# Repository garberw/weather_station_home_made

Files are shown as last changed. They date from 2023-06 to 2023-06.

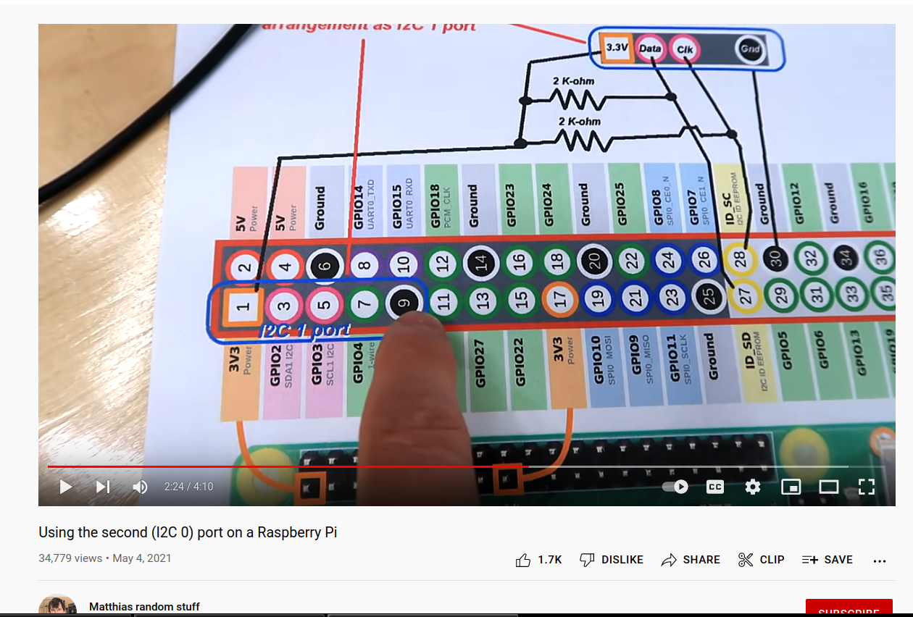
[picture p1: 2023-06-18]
raspi_user/weathere_python_service/util/Matthias_random_stuff_raspi_i2c_bus0.png

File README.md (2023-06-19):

# weather_station_home_made

Suite of two home made weather stations using raspberry pi and arduino.  Also third weather station with home made indoors part and Acurite Atlas outdoors part.  Designed for use with weewx software.  

You would need a great many parts to build any of these three weather stations.  Consequently I do not expect many people to use this github project directly.  If I had to recommend one of the three stations it would be "green".  This github project is useful for:
(A) people who have an interest in using weewx with more than one weather station
(B) people who are interested in modbus especially with weather sensors
(C) people who want examples of how to customize weewx

here is the general layout ...

(0) hostname weathers raspberry pi 4b is the weewx server.
The server accepts input from three weather stations (weewx_atlas, weewx_green, weewx_wmod).  The server stores weather data in a separate sqlite3 database for each weather station and produces a set of graphs every few minutes.  The graphs are available as web pages and weathers also runs an nginx webserver.  The weathers server should be manipulated remotely from a desktop.  All development should take place on the desktop (preferably in ~/git/weather_station_home_made/) and be pushed to weathers and the other raspis using the scripts in $GIT_HOME/bin/wg-arduino-* and $GIT_HOME/bin/wg-WEATHER-*.

(1) weewx_atlas (a weewxd systemd service)
Outdoors hardware is Acurite Atlas (TM).  The radio signal from the atlas is received by and RTL-SDR radio dongle hooked up by usb to weathers.  Weewx uses the weewx-sdr driver (not by me) which in turn uses rtl-433 (not by me) to control the dongle and read the radio data printed on the usb connection.  Indoors hardware is Arduino Adafruit ItsyBitsy M4 nicknamed wpa.  This wpa reads the indoors temperature, pressure and humidity using an Adafruit BOSCH bme688 breakout board.  The wpa Arduino is hooked up to weathers over another usb serial port ttyACMwa.  This is connected to weewx by a custom weewx service found in WEEWX/weewx-atlas.  This weather station has excellent uptime but it had a glitch:  gaps in the weewx database data due to nulls (python Nones).  The gaps were fixed by handling the indoors data with a weewx service I wrote.  The weewx-sdr driver and my service together keep pace with the input from the two usb ports as it arrives.

(2) weewx_green (a weewxd systemd service)
This was an attempt to make the most robust and simple weather station possible and it succeeded.  It has almost perfect uptime and no errors.
The outdoors part is a raspi02w with hostname weathere (for external) with I2C sensors for light and UV and an interrupt driven handler for the rain bucket switch.  Anemometer is made by the company Renke and has modbus output.  Also temperature is Taidacent SHT30 and has modbus output.  I wrote a tiny modbus library.  The outdoors raspi runs a systemd service also called "weathere".  This service controls all the sensors and simply prints the result to /tmp/weathere_final.dat.  The indoors part of the weather station is a raspi02w with hostname weatherg (for green) which is hooked up to an Adafruit Itsy Bitsy M4 Arduino which controls another BME688 temperature pressure and humidity sensor.  The weatherg runs a systemd service also called "weatherg".  This also simply prints the output from the bme688 on /tmp/weatherg_final.dat.  The driver for weewx simply scps (secure copies) the two files to weathers!  Stupid but flawless.

(3) weewx_wmod (a weewxd systemd service)
This is much more complicated.  Outdoors there are two modbus sensors:  the anemometer (same Renke model but currently absent) and the temperature and humidity sensor (another SHT30).  The original design was to place the light sensor separate to keep it out of the shade and so on for each sensor.  Connecting the modbus wires to the central outdoors modbus client (wpc) I had too many bad connections.  I would have to have better hardware to do this.  The light and the rain each had their own arduino (wpl and wpr) and acted as a modbus sensor/server; I just crammed them into the same enclosure as the client wpc and used shorter wires to connect them all.  The client wpc is also a LoRa radio transmitter and sends the signal to the indoors.  The wpw arduino indoors is the radio receiver.  It also has the indoors sensors (you guessed it another bme688).  The arduinos  have a much more complicated modbus library I wrote in c++.

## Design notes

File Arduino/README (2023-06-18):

TODO ================
timing when usb not plugged in;
ttyUSB; avrdude requires replug usb;
weewx driver; json; pack; unpack (parse);
power;
  diodes;
  and LoRa; check radio range;
fixed
rain is a pull down pin not a pull up;

ver56 ===============
updated error handling macros and added backtrace based on FUNC_BEGIN pushing
__func__name__ on a stack in static_serial_print; changed most macros from
ERROR_RETURN to ERROR_CONDITION which does backtrace; ERROR_CONDITION is
for point where error would originally be raised or thrown;
ERROR_RETURN is for returning function with subsidiary error in descendents;
ERROR_CATCH catches any errors that have happened so far accumulated in weather_exception;
weather_exception is reset at beginning of main loop;

ver55 ===============

ver54 ===============
added two locks LOCK1 and LOCK2 for FUNC_BEGIN which turns ser_print printing on or off
by looking up boolean value (on or off) in hash table of combinations (file + function)
names from variables defined by compiler next pushing on/off value on a stack;
LOCK1 is static and precomputes hash lookup based on variables on first execution
and not thereafter; LOCK2 just gets value stored in LOCK1; avoids computing hash at run time;
also simplified select* functions in weather_lib_wmod;
runs but not debugged extensively;

ver53 ===============
merge wdat and sdat into wdat including both indoors and outdoors;
pythonic index sets into wdat data table replace explicit repetitive pack and print statements;
now all printing of weather data except diagnostics is done by weather_data class / lib;
everything has new names supposed to be more symmetrical; more symmetrical structure;
all drivers patched; moved compilation to electron and all loads (flash arduino)
done by respective raspberry pi weathers (wpa; wpw;); weatherw (wpc; wpl; wpr;); weatherg (wpg);
option in "makefile" (wg-arduino-build.sh) to compile anything given load host and usb port;
this allows short test programs e.g. in ~/Arduino/utility_bug;
created ~/Arduino/deprecated for old stuff;
emacs supports makefile and "F5" "F2" and "shift F2" keys for global search and replace;
"symmetrical" names keep deprecated separate at top of "F5" list; mark whole directory "m"
then unmark deprecated "u" before search "F2";
created new udev rule that automatically sets baud and "stty -F raw" obviating need for "ssss"
alias (wg-arduino-stty.sh) script;
figured out how to reset with button on arduino; tap it twice quickly; should turn green;
added Adafruit watchdog timer;
runs but not debugged extensively;

ver52 ===============
a few minor changes; runs;

ver51 ===============
reverted to version 49 then developed automatic way of creating header file
to turn print statements on or off based on compiler "macros" (actually not
macros) __func__ and __FILE__; stored in hash table; look up at beginning of
each function; constructor LOCK pushes "in-use" on stack; destructor pops off
on function exit; to make it more efficient
(1) remove bounds check in in-use stack table lookup;
(2) remove redundant FUNC_BEGIN which call slow load (hash table lookup);
runs; not thoroughly debgugged; was crashing requiring reset button;

ver50 ===============
version with exception handling; never got it to work;
believe they may simply not be supported;
see calendar .o comments and "todo-done" log of work done in directory aa-aa;

ver49 ===============
I think it works; split atlas into atlas and green; no more compiler macros -D in
platform_local.txt or anywhere; created weather_indoors2 library
to copy and print iaq data to weewx; revised .emacs and ~/bin/wg-arduino-build.sh script;
compiles on weathers; rsync's everything then uploads remotely when needed;

ver48 ===============
bme688 working with iaq and co2 for all sensors; fixed; but set delay to zero for all loop();

ver47 ===============
added support for eeprom auto calibration

ver46 ===============
factored weather_basic into weather_main; weather_satellite; weather_basic;
renamed weather_main to weather_outside;
renamed weather_satellite to weather_inside;
renamed weather_basic (minus above two) to weather_util;
this enables me to work on weather_iaq2 without taking equipment inside to flash;
factored weather_iaq into weather_iaq1 and weather_iaq2;
weather_iaq1 is original David Bird algorithm;
weather_iaq2 is driver for BOSCH BSEC closed source library;
everything compiles; runs;
next version will install auto calibration with store to EPROM every 6 hours;
see BOSCH example;

ver41 ===============
rtc enabled with sync from weatherb to wpa over usb serial; works;

ver40 ===============
next version will have rtc enabled with sync from weatherb to wpa over usb serial;

ver39 ===============
changed iaq from int to float

ver38 ===============
production run

ver37 ===============
updated for aht20 temperature sensors inside box; polished somewhat;
added 6 words (12 bytes) per server to modbus messages;

ver36 ===============
implemented blocking receive with timeout; runs really fast; python timing and pattern
scripts have perfect output; still needs to be gone over with a find-toothed comb for bugs;

ver35 ===============
runs almost entirely;
ported from adafruit metro mini to adafruit itsy bitsy express m4 (ATSAMD51G);
this is a 32 bit arduino; 120MHz 512KB flash 192KB ram;
previously metro mini 16 bit arduino; 16MHz; 32KB flash; 2KB ram (that's right 2KB);
it was suggested that at 71% ram memory use there was a possible stack overflow so I upgraded;
rerun python modbus communication timing and pattern scripts; pattern means
find cycles of process upstream/downstream for each sensor and client;
possible bug due to 64k arduino read buffer size and data input buffer DATA_MAX=29
and one of the typical modbus message lengths forming a cycle in the input buffer
somehow but not aligned with the beginning of the message at the beginning of the buffer;
still need to check pull up resistor on rain switch and find if read buffer is still 64 bytes;
and change the key debounce delay time on the rain switch;

ver34 ===============
weather_station; fix program; write python script to measure and plot timing;
there can be at most two modbus writes per cycle of client assuming
client is slowest loop (slower than all servers per loop);
SoftwareSerial (RS485Serial) has a circular input buffer which is
only 64 bytes on UNO; when full it discards further input (overflow);
to prevent overflow add delay to client loop to make it slowest;
new main read function works using match...() functions;
meanwhile servers (sensors) loop reading only except writing zero or one
times per cycle of main loop; scripts in ~/arduino_LOG/timing* for
histogram of cycle times; max is about two or three seconds so
make main loop five second delay; scripts in ~/arduino_LOG/pattern* for
checking communication print statement debugging output;
------ T TEMP   CRX DATA
------ 1 TEMP   CRX DATA
------ 2 ERROR  ERROR
this shows each cycle of loop() that at most (if working) two messages
were sent and from TEMP server and "CRX DATA" means it was CRX DATA
(client receive data reply) or CTX REQUEST (client transmit request)
arduinos were studied for about 580 cycles and the same send/receive
pattern happened every time; client receives server 1,2,3,1,2,3,1,2,3,...
(wind unplugged); server cycle reads spurious messages from other servers
before getting request addressed to itself;
Also crashed when taken outside; radio_rx loop with 20 attempts was too short;
increased radio_rx loop to 50 and found it succeeded after 22 attempts usually;
maybe this caused it to get stuck never receiving; now it should always succeed
since 50 is plenty big enough and not near 20 or a multiple thereof;

ver33 ===============
figured out timing better; rewrote main "read()" function; does not work;
will rewrite again using Serial.readbytes() and simply scan buffer();

ver32 ===============
made "drivers" (client/server .ino files) more symmetrical with process_upstream
and process_downstream instead of process_sensor; few ERROR_CATCH
reduced compiled memory size; simplified bounds_checked_array_1 and removed
bounds_checked_array_2; runs okay; added 1000 msec delay to wpi (weather_radio_rx);
this delay makes it receive successfully each time;
added much better print-statement debugging; added skip-leading-blanks (zeros) to
weather_modbus read() function; added "skip blanks" to print statement debugging;

ver31 ===============
has two types of errors; normal failures and error exceptions (should not happen)
next version should make never crash or lock up; should always recover;

ver30 ===============
has excessive use of ERROR...; everything is an ERROR not a normal failure;
next version will have two types of errors; normal failures and error (should not happen)
exceptions (ERROR_CATCH; ERROR_...)

ver29 ===============
removed bit_field; added bounds_checked_array; next version will attempt tab stops for
variable printing; has bugs;

ver28 ===============
before major modifications such as bounds_checked array;

ver27 ===============
installed (long) before 8/16/22
created weatherwm weather station and put wmod and weatherwm outside;
first full installment; finished; now debugging in real use begins;
crashing regularly; may be from heat;

ver26 ===============
started reading datasheets;
back to normal but lux is all messed up;
doing regression to get correct fit for all quantities;
rain is done; wind will not be done;
humidity temperature and pressure are shifted by adding a constant;
average must equal average of atlas;
lux and light count are multiplied by a constant; no adding;
least squares fit to atlas; x = atlas; y = wmod;
constant a = sum(x*y)/sum(x*x);

ver25 ===============
gave up on radiohead ask library; integrated changes for BME688 temp/humid/press sensor
from ver24; back to <RH_RF95.h> library; included every sensor in weewx_wmod driver;
reduced memory to make it fit on weather_radio_rx which was very full;
now weather_radio_rx uses 71% ram; runs under weewx;

ver24 ===============
changed weather_radio_rx to a transmitter sensor weather_satellite using radiohead ask library;
changed weather_client to transmit using radiohead ask library;
tried to get rtl-sdr to be the receiver;
modified driver for rtl_433 in /home/garberw/git/rtl_433/src/devices/radiohead_ask.c
have to use rtl_433 with rtl_tcp instead of rtl-sdr sub-driver or "back end";
rtl_tcp does same thing but reads off usb port and "publishes" it on tcp for all to read;
only one can read usb port at a time;
all compiles; could not even run demo for radiohead ask;
connected miso of client to mosi of satellite and vici versa (with wires) and this worked
but that is not so helpful; reverting to ver23;

ver23 ===============
fine tuning;
before changing weather_radio_rx to a transmitter sensor using radiohead ask library;
before moving weather_client to transmit using radiohead ask library;
experimenting with using rtl-sdr as the receiver;
modified driver for rtl_433 in /home/garberw/git/rtl_433/src/devices/radiohead_ask.c

ver22 ===============
rain server; calibrate;
figure out max rain speed in buckets per sec;
h = N h0;
where h0 = BUCKET_VOLUME = 0.0375 cm/tip;  (it is a height not a volume);
can measure at least f = 1 tips / sec;
rain rate = h0 [cm/tip] * f [tip/sec] = 0.0375 [cm/sec]=0.375 [mm/sec] * 3600 [sec/hr] = 1350 mm/hr
fastest recorded rate is 0.085 mm/sec = 305 mm/hr
Another way;
V = 500cc in 257 tips; say 257 seconds;
A = area of rain gauge rain catcher = 51.84 cm^2;
rain rate = (500 [cm^3] / 51.84 [cm^2]) / (257 [sec]) = 0.375 [mm/sec]

ver21 ===============
made radio buffer about half as big; now radio_rx and client fit in memory;

ver20 ===============
added timing measurements;
note memory use very low on client 75% right on borderline;
timing; optimize delay() statements;
  main idea;
    client read timeout >= (1*(time to read server sensor) + (time to transmit/receive));
    client read timeout >= total loop time server;

ver19 ===============
updated utility_temp and utility_wind;
send wdat.m_done as bitvector over radio;
only done if client receives data from server;
finished if done or count >= max_count;
memory use low enough;
light server; can not turn off LEDs; no way to do this other than painting them black or
covering with tape;
decided to debounce rain switch with longer interrupt time instead of using a capacitor;
decided not to  replace velcro with mounting plates;
do not need any capacitors or pull-up resistors and pull-down resistors; built in to dev board;
need second hardware serial port; share Serial on pins 0,1;
note that wind minimum reading is 0.5 meters/sec which is not that sensitive;
need a strong fan to test;
no obvious problem with boot of temp sensor;
usb plugged in but not wall transformer; need to use diodes;

ver18 ===============
get wind working; create utility_wind; set baud of wind to 9600;
make current measuring barrel jack device;
measure current with meter; 85 mA at 12 V without temp fan; 200 mA at 12 V with temp fan;
radio only makes small blip on ammeter;

ver17 ===============
print statement debugging; turn on or off within program; silent mode;
compiles; runs all sensors; radio working;
added toggle for print statement debugging
improved weather_excpetion;
both use bit_field class;
debounce rain gauge switch using Lady Ada's switch tutorial;
increase debounce delay; works okay;
why not make it really large;
note; often when boot fails you have to replug the usb cable;
does not halts boot if usb not connected; while (!Serial); adafruit radio docs have comment;
  adafruit comment included in setup function in all code;
  unplug all usb; replug power; plug in radio_rx; you __DO__ get a signal; even temperature;
decide not to optimize radio broadcasts and power output since we are using wall power;
perma-proto boards; velcro; check if it causes static electricity; no not really;

ver16 ===============
compiles; runs all sensors; radio working;
made option to give up after about 5 tries;
temperature bug was swapped bytes;
using arduino-cli; problem with ttyUSBxx and stty (and avrdude ????);
reason it fits in memory is probably conversion
of all strings to format_string (F("example"))
not rewrite of program stupidly !!!!;

ver15 ===============
compiles
runs most sensors but not temperature;
radio fixed;
next version will try arduino-cli (command line interface);

ver14 ===============
compiles
somewhat runs

ver13 ===============
made client and all programs fit in memory;
then did a big edit to get radio working;
moved most stuff to libraries;
created radio library;
does not compile yet;

ver12 ===============
get sensors working concurrently;
no real understanding of how this works;
(one times time to read server sensor plus
time to send/receive) should be timeout for read on client;
light is slower and has several missed frames;
next version;
hopefully debounce rain gauge switch using Lady Ada's
switch tutorial and or a capacitor;
get one at electronics plus in San Rafael;
running very low on ram (not flash) on light server; fix this;
idea behind timing;
check for timing when not plugged in to serial usb ports;
calibrate rain gauge;

ver11 ===============
Juan Bester http://www.zihatec.de SimpleModbusSlave;
SimpleModbusSlave frame buffer and timing idea fixed program;
Also do not print to serial when using other software serial port;
next version get sensors working concurrently;
fully working for each sensor separately;
set tr (timeout read) not T15 or T35 to zero
for each sensor server;
servers miss a lot of messages from client;
probably min tr to set for client is twice average
loop time for server (with server tr (timeout read) = 0);
tr for client has been set to low values;
must account for time for server to perform computation
or sensor measurement e.g. light is a bit slow
about 1500 milliseconds including modbus read/write;

ver10 ===============
copied SimpleModbusSlave;
does not compile;
decided was unnecessary complication;
will just use proper timing introduced by that program;

ver09 ===============
uses interrupts;
rain not communicating over modbus;
others okay;

ver08 ===============
rain working except for communicating with client;
next version hopefully will use interrupts;
otherwise as-is we have to divide main loop time
into mostly polling pin 2 for button presses
(bucket tips) unless a request is pending;

ver07 ===============
new combined read/write and write/read functions;
wait on "available" for read;
working intermittently when set delay to 1000 msec;
syncs every time when starting;
does not sync (read fails) every other time after about five minutes;

ver06 ===============
new combined read/write and write/read functions;
not working;

# eee eof

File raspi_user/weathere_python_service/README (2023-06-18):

weathere is short for "WeatherGreenOutdoor"

ver00
still trying to get minimalmodbus to work.
raspi_temp with homemade modbus code from wmod (arduino weather station) works great.

ver01
neatened it up.

ver02
added rain code with interrupts.  works.

ver03

ver04
worried by failure; was loose wire; was getting exactly six bad chars before each reply;
minor changes.  rewrote client_tx_rx (request_reply).

ver05
working; next version will start on weewx driver server;

ver06
first draft of driver for weewx;

# eee eof

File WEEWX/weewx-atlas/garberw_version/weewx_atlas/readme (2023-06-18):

NOT UPDATED from original weewx-sdr driver; not applicable N/A   -- William Garber

weewx-sdr
Copyright 2016-2022 Matthew Wall
Distributed under terms of the GPLv3

This is a driver for weewx that captures data from software-defined radio.
It works with open source rtl sdr software that in turn works with
inexpensive, broad spectrum radio receivers such as the Realtek RTL2838UHIDIR.
These devices cost about 20$US and are capable of receiving radio signals from
weather stations, energy monitors, doorbells, and many other devices that use
unlicensed spectrum such as 433MHz, 838MHz, and 900MHz frequencies.

===============================================================================
Hardware

Tested with the Realtek RTL2838UHIDIR.  Should work with any software-defined
radio that is compatible with the rtl-sdr software.  Uses the modules in
rtl_433 to recognize packets.

Output from many different sensors is supported.  To see the list of supported
sensors, run the driver directly with the list-supported action.

If a sensor is supported by rtl_433 but not by weewx-sdr, it is a fairly simple
matter of writing a parser for that sensor within weewx-sdr.  Things are a bit
more complicated if a sensor is not supported by rtl_433.

===============================================================================
Installation

0) install pre-requisites

a) install weewx
    http://weewx.com/docs.html
b) install rtl-sdr
    http://sdr.osmocom.org/trac/wiki/rtl-sdr
c) install rtl_433
    https://github.com/merbanan/rtl_433

1) download the driver

wget -O weewx-sdr.zip https://github.com/matthewwall/weewx-sdr/archive/master.zip

2) install the driver

sudo wee_extension --install weewx_atlas.tar.gz

3) configure the driver

sudo wee_config --reconfigure --driver=user.weewx_atlas --no-prompt

4) run the driver directly to identify the packets you want to capture

cd /home/weewx
sudo PYTHONPATH=bin python bin/user/weewx_atlas.py --cmd="rtl_433 -M utc -F json"

5) modify the [SDR] section of weewx.conf using a text editor

- create a [[sensor_map]] for the data you want to capture
- possibly modify the 'cmd' parameter

6) start weewx

sudo /etc/init.d/weewx start

===============================================================================
How to run the driver directly

Run the driver directly for testing and diagnostics.  For example, if weewx
was installed using setup.py:

cd /home/weewx
sudo PYTHONPATH=bin python bin/user/sdr.py --help

If weewx was installed from deb or rpm:

sudo PYTHONPATH=/usr/share/weewx python /usr/share/weewx/user/sdr.py --help

===============================================================================
Configuration

Use the [SDR] section of the weewx configuration file (nominally weewx.conf) to
adjust the driver configuration.

The default configuration uses this command:

rtl_433 -M utc -F json

Specify different options using the cmd parameter.  For example:

[SDR]
    driver = user.sdr
    cmd = rtl_433 -M utc -F json -R 17 -R 44 -R 50

The rtl_433 executable emits data for many different types of sensors, some of
which have similar output.  Use the sensor_map to distinguish between sensors
and map the output from rtl_433 to the database fields in weewx.

Here are some examples:

# collect data from Acurite 5n1 sensor 0BFA and t/h sensor 24A4
[SDR]
    driver = user.sdr
    [[sensor_map]]
        windDir = wind_dir.0BFA.Acurite5n1Packet
        windSpeed = wind_speed.0BFA.Acurite5n1Packet
        outTemp = temperature.0BFA.Acurite5n1Packet
        outHumidity = humidity.0BFA.Acurite5n1Packet
        rain_total = rain_total.0BFA.Acurite5n1Packet
        inTemp = temperature.24A4.AcuriteTowerPacket
        inHumidity = humidity.24A4.AcuriteTowerPacket

# collect data from Acurite 986 fridge/freezer sensor set 1R and 2F
[SDR]
    driver = user.sdr
    [[sensor_map]]
        extraTemp1 = temperature.1R.Acurite986Packet
        extraTemp2 = temperature.2F.Acurite986Packet

# collect data from Acurite 06002RM t/h sensor 3067
[SDR]
    driver = user.sdr
    [[sensor_map]]
        inTemp = temperature.3067.AcuriteTowerPacket
        inHumidity = humidity.3067.AcuriteTowerPacket

# collect data from two Hideki TS04 sensors with channel=1 and channel=2
[SDR]
    driver = user.sdr
    [[sensor_map]]
        outBatteryStatus = battery.1:9.HidekiTS04Packet
        outHumidity = humidity.1:9.HidekiTS04Packet
        outTemp = temperature.1:9.HidekiTS04Packet
        inBatteryStatus = battery.2:9.HidekiTS04Packet
        inHumidity = humidity.2:9.HidekiTS04Packet
        inTemp = temperature.2:9.HidekiTS04Packet

# collect data from Fine Offset sensor cluster with serial number 0026
[SDR]
    driver = user.sdr
    [[sensor_map]]
        windGust = wind_gust.0026.FOWH1080Packet
        outBatteryStatus = battery.0026.FOWH1080Packet
        rain_total = rain_total.0026.FOWH1080Packet
        windSpeed = wind_speed.0026.FOWH1080Packet
        windDir = wind_dir.0026.FOWH1080Packet
        outHumidity = humidity.0026.FOWH1080Packet
        outTemp = temperature.0026.FOWH1080Packet

To figure out the sensor identifiers, run the driver directly, possibly with
the --debug option.  Another option is to run weewx with the logging options
for [SDR] enabled to display the sensors found by rtl_433, the sensor
identifiers used by weewx, and the sensors actually recognized by weewx.

[SDR]
    driver = user.sdr
    log_unknown_sensors = True
    log_unmapped_sensors = True

By default the logging options are False.

===============================================================================
How to diagnose problems

First try running the rtl_433 application to be sure that it works properly:

sudo rtl_433

Be sure that you are capturing data from the sensors you care about.  To do
this, you might want to experiment with some of the options to rtl_433.  For
example, this will eliminate extraneous output (-q), and use UTC for timestamps
(-M utc):

sudo rtl_433 -M utc -F json

If you know exactly which sensors you want to monitor, try the -R option to
reduce the clutter.  For example,

sudo rtl_433 -M utc -F json -R 9 -R 31

Once that is working, run the driver directly to be sure that it is collecting
data from the rtl_433 application.

cd /home/weewx
sudo PYTHONPATH=bin python bin/user/sdr.py

Make note of the sensor identifiers.  Each identifier is a three-part string
consisting of the observation, sensor id, and rf packet type, separated by
periods.  You need these in the sensor map to tell weewx the association
between sensors and database fields.

In the weewx configuration file, enter the rtl_433 options (if necessary) and
the sensor map.  Then run weewx directly in one shell while you monitor the
weewx log in a separate shell:

in shell 1:
cd /home/weewx
sudo ./bin/weewxd weewx.conf

in shell 2:
tail -f /var/log/syslog

At this point, verify that the mapping you made in the weewx configuration file
is working as you intend.  You should see data from your sensors in the weewx
LOOP and REC output.  If not, check the log file.  Use the logging options in
the [SDR] section of the weewx configuration file to help figure out which
sensors are captured, recognized, and parsed.

Once you are satisfied with the output when running weewx directly, run weewx
as a daemon and configure rc script or systemd to run weewx at system startup.

sudo /etc/init.d/weewx start

===============================================================================
Environment

The driver invokes the rtl_433 executable, so the path to that executable and
any shared library linkage must be defined in the environment in which weewx
runs.

For example, with rtl_433 and rtl-sdr installed like this:

/opt/rtl-433/
/opt/rtl-sdr/

one would set the path like this:

export PATH=/opt/rtl-433/bin:${PATH}
export LD_LIBRARY_PATH=/opt/rtl-sdr/lib

Typically this would be done in the rc script that starts weewx.  If rtl_433
and rtl-sdr are install to /usr/local or /usr, then there should be no need
to set the PATH or LD_LIBRARY_PATH before invoking weewx.

If you cannot control the environment in which weewx runs, then you can specify
the LD_LIBRARY_PATH and PATH in the weewx-sdr driver itself.  For example:

[SDR]
    driver = user.sdr
    cmd = rlt_433 -M utc -F json
    path = /opt/rtl-433/bin
    ld_library_path = /opt/libusb-1.0.20/lib:/opt/rtl-sdr/lib
    [[sensor_map]]
        ...

===============================================================================
libusb

I have had problems running rtl-sdr on systems with libusb 1.0.11.  The rtl_433
command craps out with a segmentation fault, and the rtl_test command sometimes
leaves the dongle in a weird state that can be cleared only by unplugging then
replugging the dongle.

Using a more recent version of libusb (e.g., 1.0.20) seems to clear things up.

===============================================================================
Support for new sensors

To add support for new sensors, capture the output from rtl_433.  To capture
output, run the driver directly and hide known packets:

PYTHONPATH=bin python bin/user/sdr.py --cmd "rtl_433 -M utc -F json" --hide parsed,out,empty

This should emit a line for each unparsed type.  For example:

unparsed: ['{"time" : "2017-01-16 15:44:51", "temperature" : 54.140, "humidity" : 34, "id" : 221, "model" : "LaCrosse TX141TH-Bv2 sensor", "battery" : "OK", "test" : "Yes"}\n']

If there is no json ouput, remove the '-F json' option to see the (deprecated)
non-json output:

unparsed: ['2016-11-04 16:12:39 :\tFine Offset Electronics, WH2 Temperature/Humidity sensor\n', '\tID:\t 38\n', '\tTemperature:\t 54.4 C\n', '\tHumidity:\t 55 %\n']

If you are not comfortable writing your own parser, post the output to the
issues section of the weewx-sdr repository and some helpful person might write
the parser for you.

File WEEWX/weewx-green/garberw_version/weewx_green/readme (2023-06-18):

weewx_green
Copyright 2022-2028 William Garber
Copyright 2014-2020 Matthew Wall
Copyright 2014 Nate Bargmann <n0nb@n0nb.us>
See the file license for your rights.
Credit to and contributions from:
  Jay Nugent (WB8TKL) and KRK6 for weather-2.kr6k-V2.1
    http://server1.nuge.com/~weather/
  Steve (sesykes71) for testing the first implementations of this driver
  Garret Power for improved decoding and proper handling of negative values
  Chris Thompstone for testing the fast-read implementation

This is a driver for weewx that captures data from the green weather station.
It is very similar to the original /home/weewx/bin/weewx/drivers/ultimeter.py
which is for Peet Brothers weather stations.
It simply reads a usb serial port which can be configured and it
discards all data except lines beginning with "!!" and ending with
some combination of '\r' and '\n'.
The binary format of this line is documented in the source code and
is compatible with the green weather station.

===============================================================================
Hardware

The green weather station is a custom home-made hobby creation.

===============================================================================
Installation

0) install pre-requisites

install weewx
    http://weewx.com/docs.html

1) download the driver

wget -O weewx_green_master.tar.gz (fixme wrong address) https://github.com/garberw/weewx_green/archive/master.tar.gz

2) install the driver

sudo wee_extension --install weewx_green_master.tar.gz

3) configure the driver

sudo wee_config --reconfigure --driver=user.weewx_green --no-prompt

4) run the driver directly to identify the packets you want to capture

cd /home/weewx
sudo PYTHONPATH=bin python bin/user/weewx_green.py 

5) modify weewx.conf using a text editor

see Configuration section below.
    
6) start weewx

sudo /etc/init.d/weewx start

===============================================================================
How to run the driver directly

Run the driver directly for testing and diagnostics.  For example, if weewx
was installed using setup.py:

cd /home/weewx
sudo PYTHONPATH=bin python bin/user/weewx_green.py --help
sudo PYTHONPATH=bin python bin/user/weewx_green.py --port=/dev/ttyUSB0

If weewx was installed from deb or rpm:

sudo PYTHONPATH=/usr/share/weewx python /usr/share/weewx/user/weewx_green.py --help
sudo PYTHONPATH=/usr/share/weewx python /usr/share/weewx/user/weewx_green.py --port=/dev/ttyUSB0

===============================================================================
Configuration

# main section Station
[Station]
    station_type = WeatherModbus

# add main section directly following [Station] section
[WeatherModbus]
    # you can assign a fixed port to USB device using udev; see below;
    port = /dev/ttyUSB0
    # time in seconds between LOOP packets.
    poll_interval = 2.5
    path = /var/tmp/weewx_green_data
    # path relative to WEEWX_ROOT
    # /home/weewx/bin/user/weewx_green.py

===============================================================================

How to diagnose problems

===============================================================================
Environment

===============================================================================

Support for new sensors

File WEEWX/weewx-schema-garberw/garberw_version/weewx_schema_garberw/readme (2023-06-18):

weewx_wmod
Copyright 2022-2028 William Garber
Copyright 2014-2020 Matthew Wall
Copyright 2014 Nate Bargmann <n0nb@n0nb.us>
See the file license for your rights.
Credit to and contributions from:
  Jay Nugent (WB8TKL) and KRK6 for weather-2.kr6k-V2.1
    http://server1.nuge.com/~weather/
  Steve (sesykes71) for testing the first implementations of this driver
  Garret Power for improved decoding and proper handling of negative values
  Chris Thompstone for testing the fast-read implementation

This is a driver for weewx that captures data from the wmod weather station.
It is very similar to the original /home/weewx/bin/weewx/drivers/ultimeter.py
which is for Peet Brothers weather stations.
It simply reads a usb serial port which can be configured and it
discards all data except lines beginning with "!!" and ending with
some combination of '\r' and '\n'.
The binary format of this line is documented in the source code and
is compatible with the wmod weather station.

===============================================================================
Hardware

The wmod weather station is a custom home-made hobby creation.

===============================================================================
Installation

0) install pre-requisites

install weewx
    http://weewx.com/docs.html

1) download the driver

wget -O weewx_wmod_master.tar.gz (fixme wrong address) https://github.com/garberw/weewx_wmod/archive/master.tar.gz

2) install the driver

sudo wee_extension --install weewx_wmod_master.tar.gz

3) configure the driver

sudo wee_config --reconfigure --driver=user.weewx_wmod --no-prompt

4) run the driver directly to identify the packets you want to capture

cd /home/weewx
sudo PYTHONPATH=bin python bin/user/weewx_wmod.py 

5) modify weewx.conf using a text editor

see Configuration section below.
    
6) start weewx

sudo /etc/init.d/weewx start

===============================================================================
How to run the driver directly

Run the driver directly for testing and diagnostics.  For example, if weewx
was installed using setup.py:

cd /home/weewx
sudo PYTHONPATH=bin python bin/user/weewx_wmod.py --help
#### sudo PYTHONPATH=bin python bin/user/weewx_wmod.py --port=/dev/ttyUSB0
#### sudo PYTHONPATH=bin python bin/user/weewx_wmod.py --port=/dev/ttyACM0
# ttyACM0 is fancier version of ttyUSB0
# see udev rules; symbolic link ttyACM0 to ttyACMwi
sudo PYTHONPATH=bin python bin/user/weewx_wmod.py --port=/dev/ttyACMwi

If weewx was installed from deb or rpm:

sudo PYTHONPATH=/usr/share/weewx python /usr/share/weewx/user/weewx_wmod.py --help
sudo PYTHONPATH=/usr/share/weewx python /usr/share/weewx/user/weewx_wmod.py --port=/dev/ttyUSB0

===============================================================================
Configuration

# main section Station
[Station]
    station_type = WeatherModbus

# add main section directly following [Station] section
[WeatherModbus]
    # you can assign a fixed port to USB device using udev; see below;
    port = /dev/ttyUSB0
    # time in seconds between LOOP packets.
    poll_interval = 2.5
    path = /var/tmp/weewx_wmod_data
    # path relative to WEEWX_ROOT
    # /home/weewx/bin/user/weewx_wmod.py

===============================================================================

How to diagnose problems

===============================================================================
Environment

===============================================================================

Support for new sensors

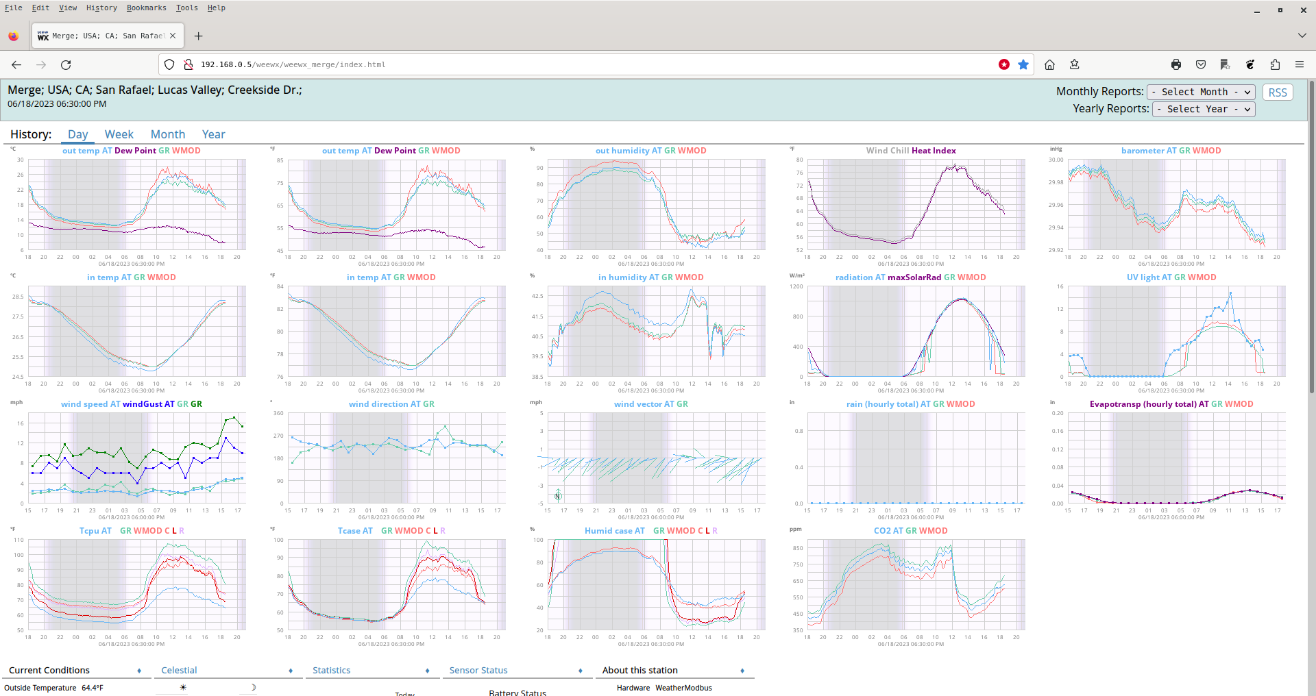
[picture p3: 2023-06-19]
doc/weewx-screenshot-2023-06-18.png

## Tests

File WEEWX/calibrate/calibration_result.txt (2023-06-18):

NEW CALIBRATION ----------
column    = inTemp
time      = 2022-10-09 10:21:19.895794
+ atl_avg = 0.0
+ calval  = 76.24000000000001
- rrrval  = -76.24000000000001
= atl_cal = 0.0

+ wmo_avg = 2.1325590755863706
+ calval  = 76.24000000000001
- rrrval  = -76.24000000000001
= wmo_cal = 2.1325590755863706

+ wwm_avg = -1.233087918215543
+ calval  = 76.24000000000001
- rrrval  = -76.24000000000001
= wwm_cal = -1.233087918215543

NEW CALIBRATION ----------
column    = inHumidity
time      = 2022-10-09 10:30:48.607000
+ atl_avg = 0.0
+ calval  = 37.0
- rrrval  = -37.0
= atl_cal = 0.0

+ wmo_avg = -5.949161919535158
+ calval  = 37.0
- rrrval  = -37.0
= wmo_cal = -5.949161919535158

+ wwm_avg = -0.8905394881584858
+ calval  = 37.0
- rrrval  = -37.0
= wwm_cal = -0.8905394881584858

NEW CALIBRATION ----------
column    = inTemp
time      = 2023-01-02 20:22:10.413396
+ atl_avg = 0.0
+ calval  = 76.24000000000001
- rrrval  = -76.24000000000001
= atl_cal = 0.0

+ wmo_avg = -1.0807954263820801e-15
+ calval  = 76.24000000000001
- rrrval  = -76.24000000000001
= wmo_cal = -1.0807954263820801e-15

+ wwm_avg = -2.669885731508208e-15
+ calval  = 76.24000000000001
- rrrval  = -76.24000000000001
= wwm_cal = -2.669885731508208e-15

NEW CALIBRATION ----------
column    = inTemp
time      = 2023-01-02 22:13:22.600121
+ atl_avg = 0.0
+ calval  = 76.24000000000001
- rrrval  = -76.24000000000001
= atl_cal = 0.0

+ wmo_avg = -0.4141071174790563
+ calval  = 76.24000000000001
- rrrval  = -76.24000000000001
= wmo_cal = -0.4141071174790563

+ wwm_avg = 0.0033710199097047346
+ calval  = 76.24000000000001
- rrrval  = -76.24000000000001
= wwm_cal = 0.0033710199097047346

NEW CALIBRATION ----------
column    = inHumidity
time      = 2023-01-02 22:14:15.352899
+ atl_avg = 0.0
+ calval  = 76.24000000000001
- rrrval  = -37.0
= atl_cal = 0.0

+ wmo_avg = -0.12131853807077138
+ calval  = 76.24000000000001
- rrrval  = -37.0
= wmo_cal = -0.12131853807077138

+ wwm_avg = -0.09208024042504852
+ calval  = 76.24000000000001
- rrrval  = -37.0
= wwm_cal = -0.09208024042504852

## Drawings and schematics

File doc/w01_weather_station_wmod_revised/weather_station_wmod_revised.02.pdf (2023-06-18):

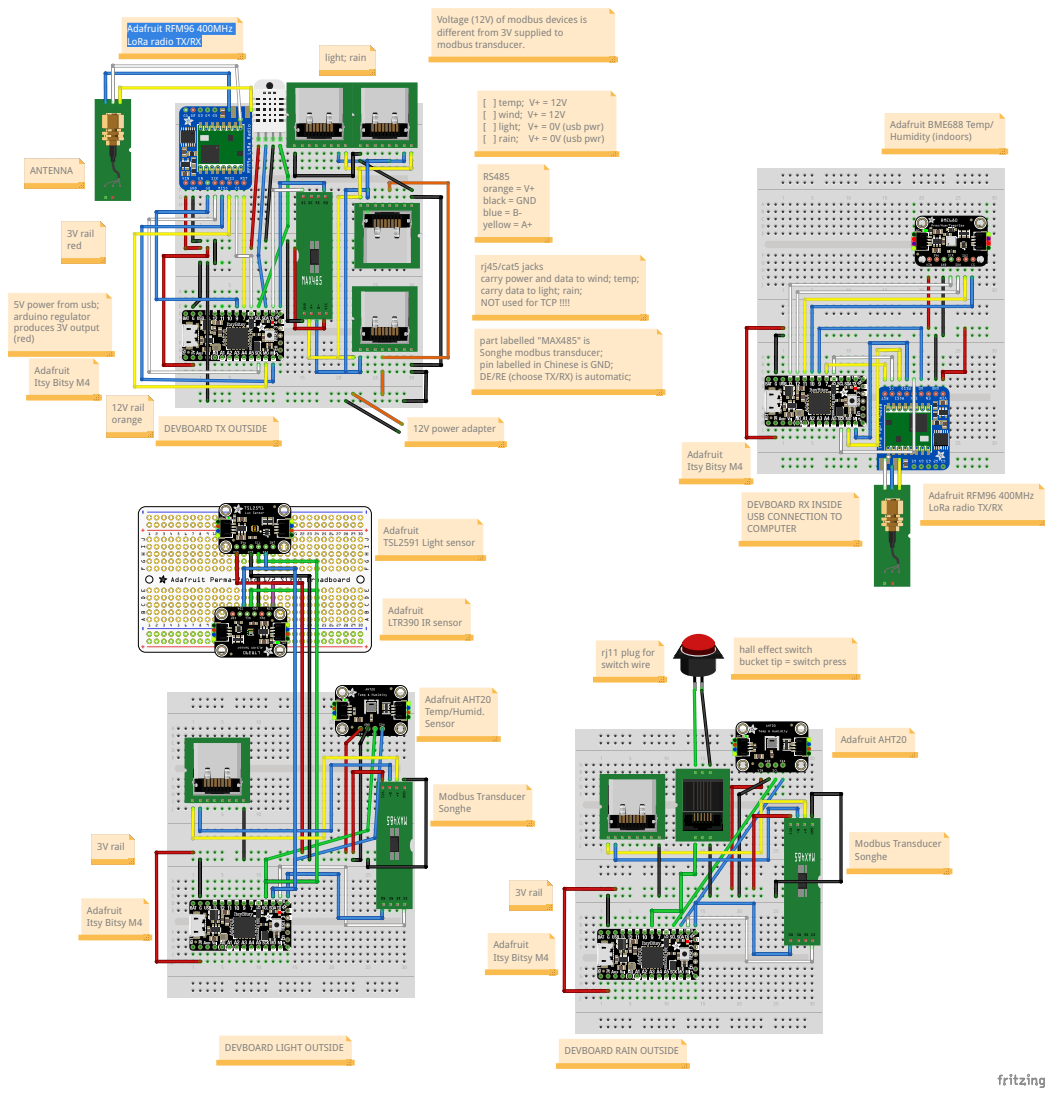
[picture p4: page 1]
12V power adapter; light; rain; 3V rail; RS485 orange = V+ black = GND blue = B- yellow = A+; ANTENNA; 12V rail orange; rj11 plug for switch wire; 3V rail red; Adafruit AHT20; Adafruit AHT20 Temp/Humid. Sensor; Modbus Transducer Songhe; Adafruit Itsy Bitsy M4; Adafruit LTR390 IR sensor; Adafruit TSL2591 Light sensor; Adafruit BME688 Temp/ Humidity (indoors)

Voltage (12V) of modbus devices is
different from 3V supplied to
modbus transducer.

Adafruit RFM96 400MHz
LoRa radio TX/RX

[ ] temp; V+ = 12V
[ ] wind; V+ = 12V
[ ] light; V+ = 0V (usb pwr)
[ ] rain; V+ = 0V (usb pwr)

rj45/cat5 jacks
carry power and data to wind; temp;
carry data to light; rain;
NOT used for TCP !!!!

5V power from usb;
arduino regulator
produces 3V output
(red)

part labelled "MAX485" is
Songhe modbus transducer;
pin labelled in Chinese is GND;
DE/RE (choose TX/RX) is automatic;

DEVBOARD TX OUTSIDE

DEVBOARD RX INSIDE
USB CONNECTION TO
COMPUTER

hall effect switch
bucket tip = switch press

DEVBOARD LIGHT OUTSIDE

DEVBOARD RAIN OUTSIDE

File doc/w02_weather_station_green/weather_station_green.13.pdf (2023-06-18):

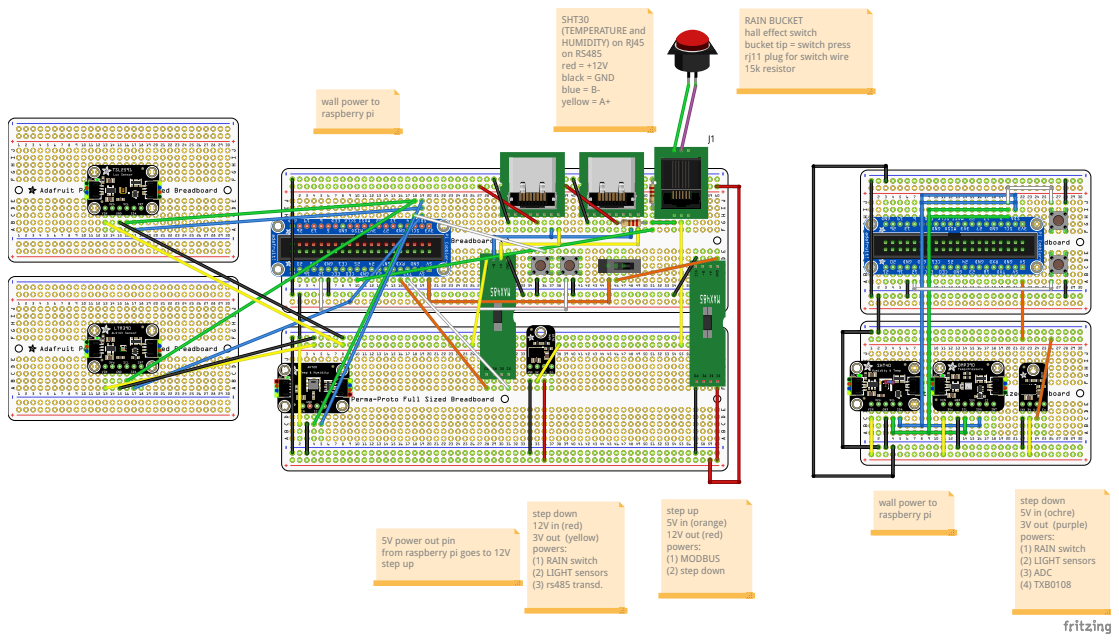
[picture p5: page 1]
SHT30 (TEMPERATURE and HUMIDITY) on RJ45 on RS485 red = +12V black = GND blue = B- yellow = A+; step down 12V in (red) 3V out (yellow) powers: (1) RAIN switch (2) LIGHT sensors (3) rs485 transd.; step up 5V in (orange) 12V out (red) powers: (1) MODBUS (2) step down; step down 5V in (ochre) 3V out (purple) powers: (1) RAIN switch (2) LIGHT sensors (3) ADC (4) TXB0108

RAIN BUCKET
hall effect switch
bucket tip = switch press
rj11 plug for switch wire
15k resistor

wall power to
raspberry pi

5V power out pin
from raspberry pi goes to 12V
step up

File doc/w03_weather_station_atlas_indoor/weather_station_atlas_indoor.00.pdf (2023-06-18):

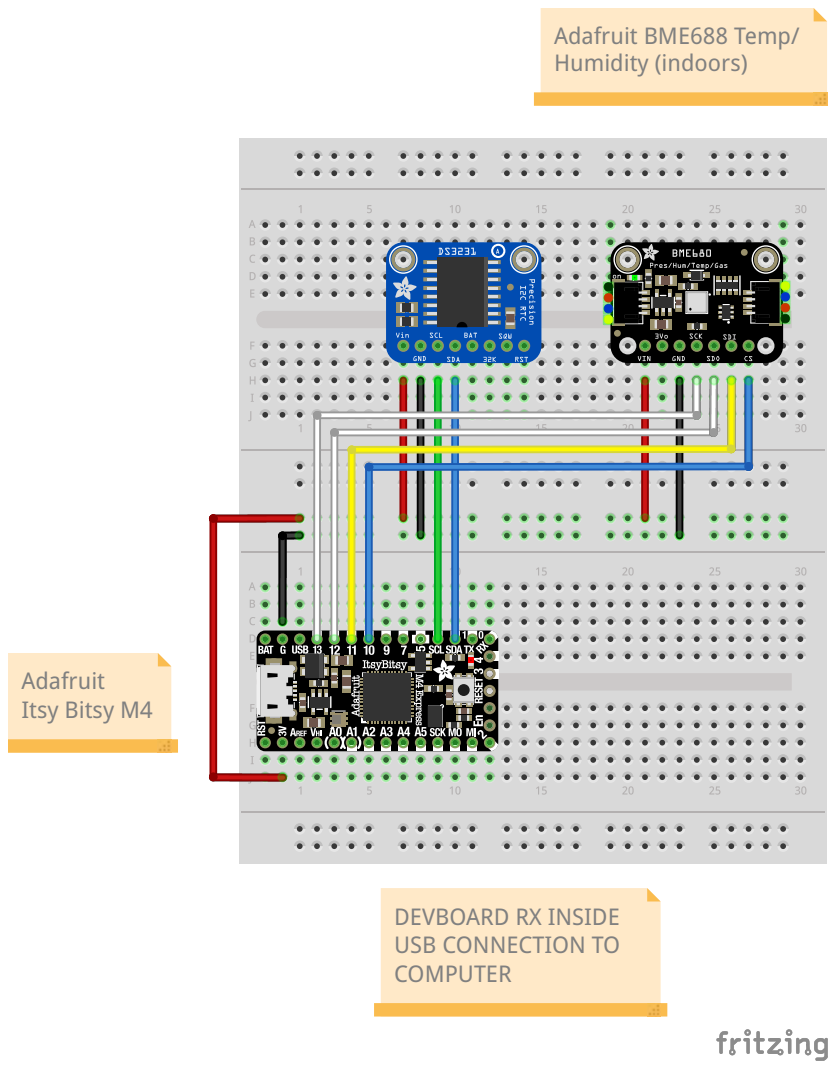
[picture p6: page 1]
Adafruit Itsy Bitsy M4; Adafruit BME688 Temp/ Humidity (indoors)

DEVBOARD RX INSIDE
USB CONNECTION TO
COMPUTER

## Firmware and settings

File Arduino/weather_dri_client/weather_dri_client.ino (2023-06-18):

/*
  Modbus RTU Weather Client

  This sketch is a Modbus RTU client.
  It reads from Modbus RTU servers (weather sensors) and outputs them to the serial monitor.
  The sensors include:

  temperature and humidity 
  wind
  light and UV
  rain

  It also uses LoRa radio to transmit (TX) them to the receiving (RX)
  arduino radio inside the house.  
  This RX arduino is hooked up by usb to a computer running weewx.
  (fixme specify weewx driver).
*/
// ctx = client transmit = request;
// crx = client receive  = reply;

// Example sketch showing how to create a simple messaging client (transmitter)
// with the RH_RF95 class. RH_RF95 class does not provide for addressing or
// reliability, so you should only use RH_RF95 if you do not need the higher
// level messaging abilities.
// It is designed to work with the other example Feather9x_RX

/* headers begin ----------------------------------------------- */

#include <weather_lib_util.h>
#include <weather_lib_timer.h>
#include <weather_lib_counter.h>
#include <weather_lib_modbus.h>
#include <weather_lib_radio.h>
#include <weather_wra_tsys.h>

/* headers end ----------------------------------------------- */
/* globals begin ----------------------------------------------- */

weather_modbus wmod;
weather_data wdat;
weather_radio wrad;
weather_timer stopw;
loop_counter_single loopc_downstream;
loop_counter_outside loopc_outside;
weather_tsys wtsys;

#define ATTEMPTS_MAX_UPSTREAM_MODBUS 20
#define ATTEMPTS_MAX_DOWNSTREAM_RADIO 20

/* globals end ----------------------------------------------- */

void setup() {
  setup_communication_ser0();
  watchdog_setup();
  setup_communication_ser1();
	wexception.clear_all();
  ser_setup();
	FUNC_BEGIN;
  
  int res = -1;
	wmod.setup_frame_array();
	stopw.setup();
  ser_println(F("Modbus Client and Radio Transmitter"));
  ser_println(F("receive from these 4 Modbus Servers:"));
	ser_println(F("(1) Sensor Temp and Humidity"));
  ser_println(F("(2) Sensor Wind Speed and Direction"));
  ser_println(F("(3) Sensor Light and UV"));
  ser_println(F("(4) Sensor Rain"));
	Serial.flush();
  wmod.setup_buffers();
	wmod.crc_debug();

	wdat.setup();

	loopc_downstream.m_title[ws_LOOPC_COUNT] = F("loopc_downstream");
	loopc_downstream.set_all_count_zero();
	loopc_downstream.set_all_done_false();
	loopc_downstream.m_count_max = ATTEMPTS_MAX_DOWNSTREAM_RADIO;

	loopc_outside.m_count_max = ATTEMPTS_MAX_UPSTREAM_MODBUS;
	loopc_outside.set_all_count_zero();
	loopc_outside.set_all_done_false();
	wtsys.setup();

  wrad.setup();

	PRINT_FREE_MEMORY(F("setup"));
	
	setup_delay();
	ERROR_CATCH;
	return;
 catch_block:
	ser_println(F("error:  setup bug"));
	wexception.print();
	weather_halt();
}

void process_downstream_radio(void) {
	FUNC_BEGIN;
	int res = -1;
	divider_line(F("C"), 55); ser_println();
	ser_println(F("radio; send the complete packet;"));
	divider_line(F("C"), 55); ser_println();
	loopc_outside.print_done();
	// stopw.start(2);
	wrad.pack_radio_frame(wdat, loopc_outside);
	// stopw.stop(2, F("pack_radio_frame"));
	// stopw.start(2);
	res = wrad.transmit_then_ack();
	// stopw.stop(2, F("transmit_then_ack"));
	if (res == 0) {
		loopc_downstream.count_loopc(WDAT_PASS);
		divider_line(F("C"), 55); ser_println();
	} else {
		loopc_downstream.count_loopc(WDAT_FAIL);
	}
	if (loopc_downstream.finished_all()) {
		wdat.set_all_data_zero();
		loopc_outside.set_all_done_false();
		loopc_outside.set_all_count_zero();
		loopc_downstream.set_all_done_false();
		loopc_downstream.set_all_count_zero();
		ser_println(F(" start reading sensors again;"));
	}
}

void process_upstream_modbus(format_string name, device_idx ws, int timeout_read) {
	FUNC_BEGIN;
	int res = -1;
	divider_line_sensor(name);
	// stopw.start(2);
	res = wmod.client_tx_rx(ws, timeout_read);
	// stopw.stop(2, F("client_tx_rx"));
  if (res == 0) {
		// stopw.start(2);
		wmod.unpack_sensor(ws, wdat);
		// wmod.unpack_tsys(ws, wdat);
		wdat.print_outside_sensor(ws);
		wdat.print_outside_tsys(ws);
		// stopw.stop(2, F("unpack print"));
		loopc_outside.increment(ws, WDAT_PASS);
	} else {
		loopc_outside.increment(ws, WDAT_FAIL);
	}
}

void process_upstream_tsys(format_string name, device_idx ws) {
	FUNC_BEGIN;
  divider_line(F("="), 30); ser_println(); ser_println(F("advanced_read_tsys begin"));
  wtsys.advanced_read_client(wdat);
  // no need to pack or unpack; it is already in wdat;
  wdat.print_outside_tsys_client();
  if (true) {
    loopc_outside.increment(ws_TSYS, WDAT_PASS);
  } else {
    loopc_outside.increment(ws_TSYS, WDAT_FAIL);
  }
}

/*
// values prior to 10/7/22
int tr_wind = 75;
int tr_temp = 320;
int tr_light = 1200;
int tr_rain = 600;
*/
// sensor gives up after several bad readings; send incomplete packet;
// to speed up light decrease integration time in configureSensor();
// tsl.setTiming(TSL2591_INTEGRATIONTIME_300MS);
void loop() {
	FUNC_BEGIN;
  int res = -1;
	wexception.clear_all();
	stopw.setup();
	stopw.start(0);
	divider_line_loop_begin();

	PRINT_FREE_MEMORY(F("loop_begin"));
	
	// uncomment to not use sensor
	loopc_outside.m_done[ws_WIND] = true;
	// loopc_outside.m_done[ws_TEMP] = true;
	// loopc_outside.m_done[ws_LIGH] = true;
	// loopc_outside.m_done[ws_RAIN] = true;
	// loopc_outside.m_done[ws_TSYS] = true;
  int tr_wind = 5000;
  int tr_temp = 2000;
  int tr_light = 2000;
  int tr_rain = 2000;

	// !(radio done) iff (loopc_outside.finished_all());
	// "else if" ensures we either send radio or measure sensors once per loop but not both
	if (loopc_outside.finished_all() && !loopc_downstream.finished_all()) {
		stopw.start(1);
		ser_println(F("======== stage 2 process_downstream_radio ALL SENSORS"));
		process_downstream_radio();
		stopw.stop(1, F("process_downstream_radio ALL SENSORS"));
	} else if (!loopc_outside.finished_wind()) {
		stopw.start(1);
		ser_println(F("======== stage 1A process_upstream_modbus WIND"));
		process_upstream_modbus(F("wind"), ws_WIND, tr_wind);
		stopw.stop(1, F("process_upstream_modbus WIND"));
  } else if (!loopc_outside.finished_temp()) {
		stopw.start(1);
		ser_println(F("======== stage 1B process_upstream_modbus TEMP"));
		process_upstream_modbus(F("temp"), ws_TEMP, tr_temp);
		stopw.stop(1, F("process_upstream_modbus TEMP"));
  } else if (!loopc_outside.finished_light()) {
		stopw.start(1);
		ser_println(F("======== stage 1C process_upstream_modbus LIGHT"));
		process_upstream_modbus(F("light"), ws_LIGHT, tr_light);
		stopw.stop(1, F("process_upstream_modbus LIGHT"));
  } else if (!loopc_outside.finished_rain()) {
		stopw.start(1);
		ser_println(F("======== stage 1D process_upstream_modbus RAIN"));
		process_upstream_modbus(F("rain"), ws_RAIN, tr_rain);
		stopw.stop(1, F("process_upstream_modbus RAIN"));
  } else if (!loopc_outside.finished_tsys()) {
		stopw.start(1);
		ser_println(F("======== stage 1E process_upstream_tsys TSYS"));
		process_upstream_tsys(F("tsys"), ws_TSYS);
		stopw.stop(1, F("process_upstream_sensor TSYS"));
	}
  // delay(100);  // commented out 4/19/22
	delay(0);    // added 10/8/22

	stopw.stop(0, F("whole loop"));
	PRINT_FREE_MEMORY(F("loop_end"));
  Serial.flush();
	ERROR_CATCH;
  watchdog_reset();
	return;
 catch_block:
	wexception.print();
  watchdog_reset();
}

// eee eof

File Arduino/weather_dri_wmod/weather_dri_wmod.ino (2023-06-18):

// -*- mode: C++ -*-
/*
  Radio Receiver and Indoor Temp Sensor

  This sketch is a radio receiver for weather sensors.
  It receives the sensor values over LoRa radio.
  It outputs them to the usb port
  where they are read by the weewx_wmod driver.
  They can be read directly by 'cat /dev/ttyUSBwi' for example.

  Example sketch showing how to create a simple messaging client (receiver)
  with the RH_RF95 class. RH_RF95 class does not provide for addressing or
  reliability, so you should only use RH_RF95 if you do not need the higher
  level messaging abilities.
*/

#include <weather_lib_util.h>
#include <weather_lib_timer.h>
#include <weather_lib_counter.h>
#include <weather_lib_radio.h>

#include <weather_wra_bme688.h>
#include <weather_wra_pas_co2.h>

/* macros begin ----------------------------------------------- */

#define HPASCAL_PER_PASCAL (0.01)
#define KOHM_PER_OHM (0.001)

// fixme this should be the only thing you need to modify for the summer
// #define STATION_WMOD_OUTSIDE_RUNNING false
#define STATION_WMOD_OUTSIDE_RUNNING true

// #define BLINK_LED true

// ATTEMPTS_WDAT_RADIO_MAX=20 was too low; took about 40 seconds;
// takes 40 seconds for client to complete a full cycle with client loop delay(5000);
// ATTEMPTS_WDAT_RADIO_MAX=50 should have at least two cycles;
#define ATTEMPTS_MAX_UPSTREAM_RADIO 50
// should almost always work
#define ATTEMPTS_MAX_UPSTREAM_SENSOR 5

/* macros end ----------------------------------------------- */
/* globals begin ----------------------------------------------- */

weather_radio wrad;
weather_data wdat;
weather_timer stopw;
loop_counter_single loopc_downstream;
loop_counter_outside loopc_outside;
loop_counter_inside loopc_inside;
weather_bme688 iaq;
weather_pas_co2 wco2;

/* globals end ----------------------------------------------- */
// fixme check this;    ??????????????????
// int res = iaq.advanced_read(wdat);

void setup(void) {
  setup_communication_ser0();
  // while (!Serial);
  watchdog_setup();
  wexception.clear_all();
  ser_setup();
  FUNC_BEGIN;
  watchdog_reset();

  stopw.setup();
  stopw.start(0);
  ser_println(F("Radio Receiver"));
  ser_println(F("receive from these 4 Modbus Servers:"));
  ser_println(F("(1) Sensor Temp and Humidity"));
  ser_println(F("(2) Sensor Wind Speed and Direction"));
  ser_println(F("(3) Sensor Light and UV"));
  ser_println(F("(4) Sensor Rain"));
  ser_println(F("send output on usb to weewx"));
  Serial.flush();

  wdat.setup();
  watchdog_reset();

  loopc_downstream.m_title[ws_LOOPC_COUNT] = F("loopc_downstream");
  loopc_downstream.m_count_max = 1;
  loopc_downstream.set_all_count_zero();
  loopc_downstream.set_all_done_false();
	
  loopc_outside.m_count_max = ATTEMPTS_MAX_UPSTREAM_RADIO;
  loopc_outside.set_all_count_zero();
  loopc_outside.set_all_done_false();
	
  loopc_inside.m_count_max = ATTEMPTS_MAX_UPSTREAM_SENSOR;
  loopc_inside.set_all_count_zero();
  loopc_inside.set_all_done_false();

  wrad.setup();
	
  iaq.setup();

  wco2.setup();

  PRINT_FREE_MEMORY(F("setup"));
  
  setup_delay();

  watchdog_reset();
  stopw.stop(0, F("setup end"));
  ERROR_CATCH;
  return;
 catch_block:
  watchdog_reset();
  stopw.stop(0, F("setup end"));
  ser_println(F("error:  setup bug"));
  wexception.print();
  weather_halt();
}

void process_downstream_weewx(void) {
  FUNC_BEGIN;
  /*
  ser_println(F("-------- call pack_weewx_frame"));
  wrad.pack_weewx_frame(wdat, loopc_outside, loopc_inside);
  ser_println(F("-------- call transmit_weewx_frame"));
  wrad.transmit_weewx_frame();
  */
  int date_time = 0;
  wdat.print_inside_outside_all_weewx(date_time, loopc_outside, loopc_inside);
  if (true) {
    ser_println(F("-------- stage loopc_downstream PASS"));
    loopc_downstream.count_loopc(WDAT_PASS);
  } else {
    ser_println(F("-------- stage loopc_downstream FAIL"));
    loopc_downstream.count_loopc(WDAT_FAIL);
  }
  if (loopc_downstream.finished_all()) {
    ser_println(F("-------- stage loopc_downstream.finished_all"));
    wdat.set_all_data_zero();
    loopc_inside.set_all_done_false();
    loopc_inside.set_all_count_zero();
    loopc_outside.set_all_done_false();
    loopc_outside.set_all_count_zero();
    loopc_downstream.set_all_done_false();
    loopc_downstream.set_all_count_zero();
  }
}

void process_upstream_radio(void) {
  FUNC_BEGIN;
  int res = -1;
  ser_println(F("wrad.receive_then_ack"));
  res = wrad.receive_then_ack();
  if (res == 0) {
    ser_println(F("-------- stage loopc_outside.increment PASS"));
    ser_println(F("-------- unpack_radio_frame"));
    wrad.unpack_radio_frame(wdat, loopc_outside);
    ser_println(F("-------- print_outside_all"));
    wdat.print_outside_all1();
    ser_println(F("-------- print_inside_all"));
    wdat.print_inside_all();
    ser_println(F("-------- loopc_outside.print_done"));
    loopc_outside.print_done();
    ser_println(F("-------- loopc_inside.print_done"));
    loopc_inside.print_done();
    ser_println(F("-------- stage loopc_outside.increment PASS"));
    loopc_outside.increment(ws_WIND, WDAT_PASS);
    loopc_outside.increment(ws_TEMP, WDAT_PASS);
    loopc_outside.increment(ws_LIGH, WDAT_PASS);
    loopc_outside.increment(ws_RAIN, WDAT_PASS);
  } else {
    ser_println(F("-------- stage loopc_outside.increment FAIL"));
    loopc_outside.increment(ws_WIND, WDAT_FAIL);
    loopc_outside.increment(ws_TEMP, WDAT_FAIL);
    loopc_outside.increment(ws_LIGH, WDAT_FAIL);
    loopc_outside.increment(ws_RAIN, WDAT_FAIL);
  }
}

void process_upstream_sensor(format_string name) {
  FUNC_BEGIN;
  int res1 = -1;
  int res2 = -1;
  divider_line_sensor(name);
  // stopw.start(2);
  res1 = iaq.advanced_read(wdat);
  ser_print("iaq return res1 = "); ser_println(res1);
  // stopw.stop(2, F("advanced_read_temp"));
  // stopw.start(2);
  res2 = wco2.advanced_read(wdat);
  ser_print("wco2 return res2 = "); ser_println(res2);
  // stopw.stop(2, F("advanced_read_co2"));
  if ((res1 == 0) && (res2 == 0)) {
    ser_println(F("-------- stage loopc_inside.increment PASS"));
    // stopw.start(2);
    wdat.print_inside_all();
    loopc_inside.increment(ws_INSIDE_TEMP, WDAT_PASS);
    // stopw.stop(2, F("print"));
  } else {
    ser_println(F("-------- stage loopc_inside.increment FAIL"));
    loopc_inside.increment(ws_INSIDE_TEMP, WDAT_FAIL);
  }
  return;
}
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
